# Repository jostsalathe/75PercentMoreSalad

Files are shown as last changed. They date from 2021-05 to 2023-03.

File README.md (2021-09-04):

# 75PercentMoreSalad

## Keychron low profile optical switches

- plate thicknes 1.2 mm
- plate cutout 14 * 14 mm²
- plate distance from pcb 1.3 mm
- pcb center hole 3.3 mm (2.4 mm below pcb surface)
- clip cutouts 11 mm apart, 2 mm wide, 5 mm long
- illumination LED within 4 and 6 mm above switch center, 3 mm long, 1.35 mm high
- 

## Stabilizer options

- Costar mounted to the PCB instead of the plate
- Kailh Choc Stabilizers (couldn't find 6.25U, yet, only [2U](https://spacecat.design/products/kailh-2u-choc-stabilizer-low-profile) ([KiCAD footprint](https://github.com/keebio/Keebio-Parts.pretty/blob/master/Kailh-PG1350-2u.kicad_mod))...)

## Parts for PCB

| Reference | Count | Value | Mfr. # | LCSC # |
|:-:|:-:|:-:|-|-|
| D1-D85 | 85 | LED IR |  |  |
| D86 | 1 | 1N5819 |  |  |
| D87 | LED Red |  |  |  |
| D88 |  |  |  |  |
|  |  |  |  |  |

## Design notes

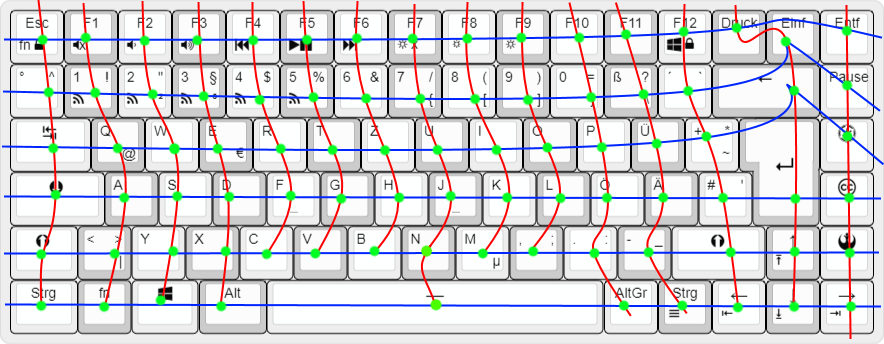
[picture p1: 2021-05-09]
75PercentMoreSaladMatrix.png

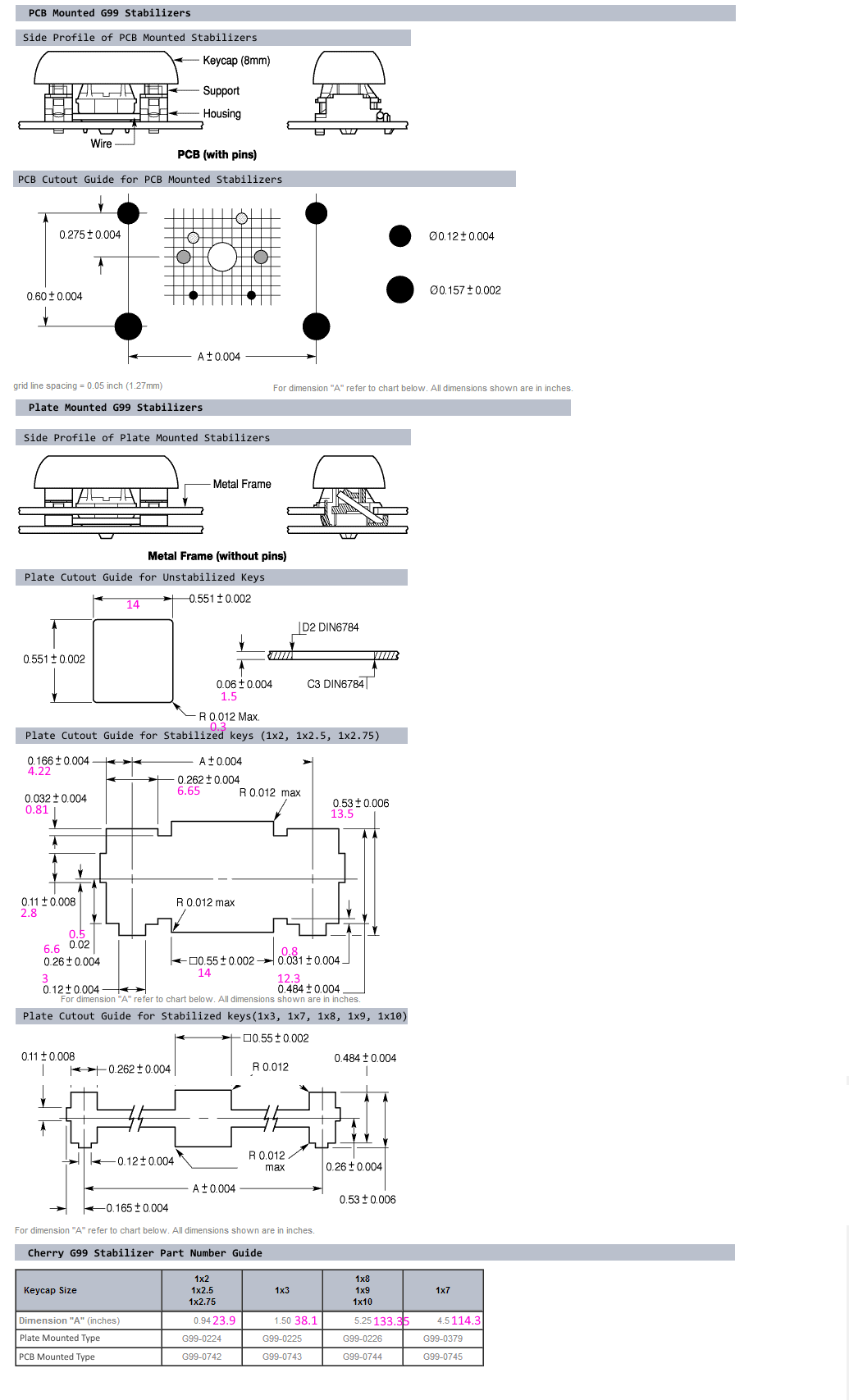
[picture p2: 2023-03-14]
case/StabiMounting.png

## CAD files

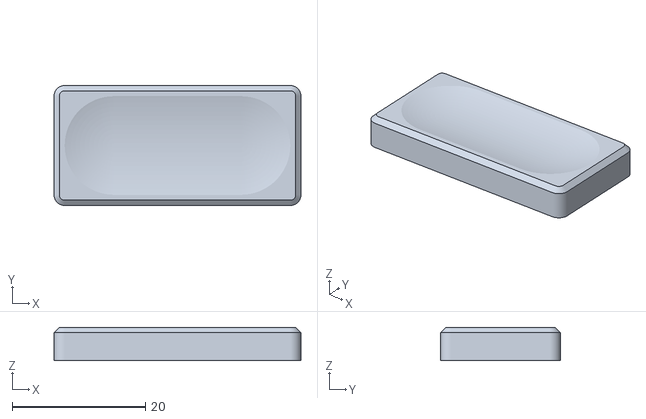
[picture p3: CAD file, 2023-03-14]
case/keycaps/keycap_full_2U.stl
37.0 x 18.0 x 5.00

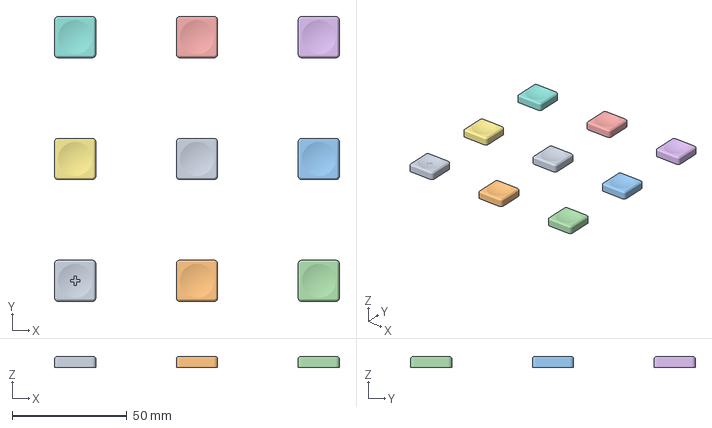
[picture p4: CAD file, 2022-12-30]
case/keycaps/keycap_full.3mf
124.0 x 124.0 x 5.00 mm
keycap_full.stl
keycap_full_home.stl

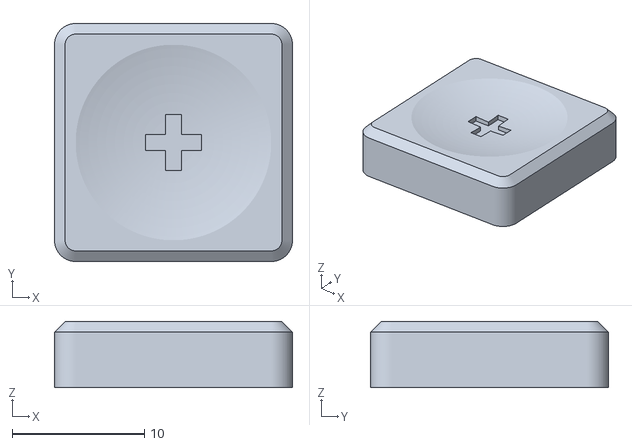
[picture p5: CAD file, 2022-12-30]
case/keycaps/keycap_full_home.stl
18.0 x 18.0 x 5.00

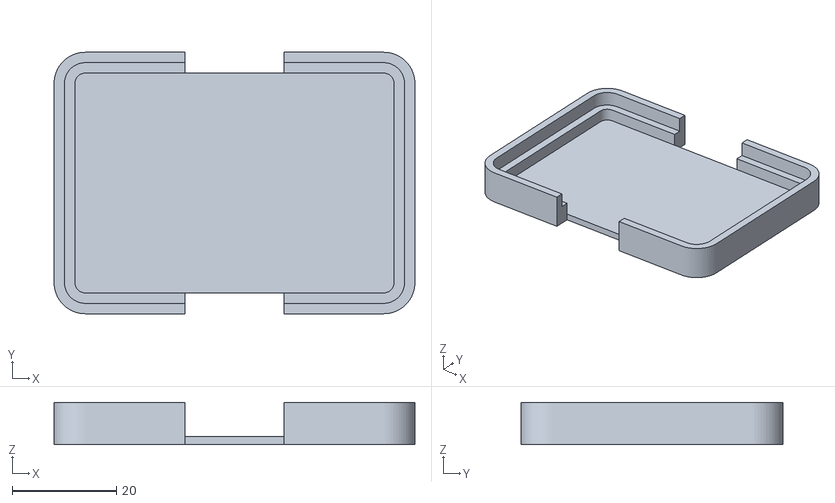
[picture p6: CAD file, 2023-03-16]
case/caseTest.stl
69.2 x 50.1 x 8.10

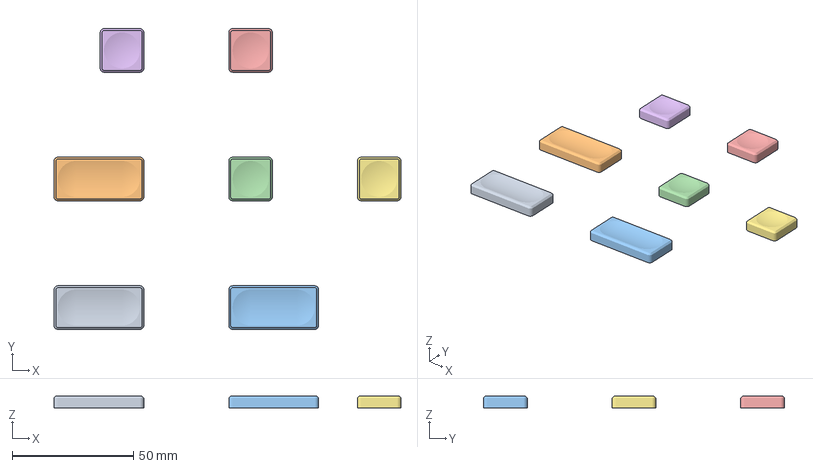
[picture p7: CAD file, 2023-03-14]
case/keycaps/keycaps_for_tester.3mf
143.0 x 124.0 x 5.00 mm
keycap_full_2U.stl
keycap_full.stl

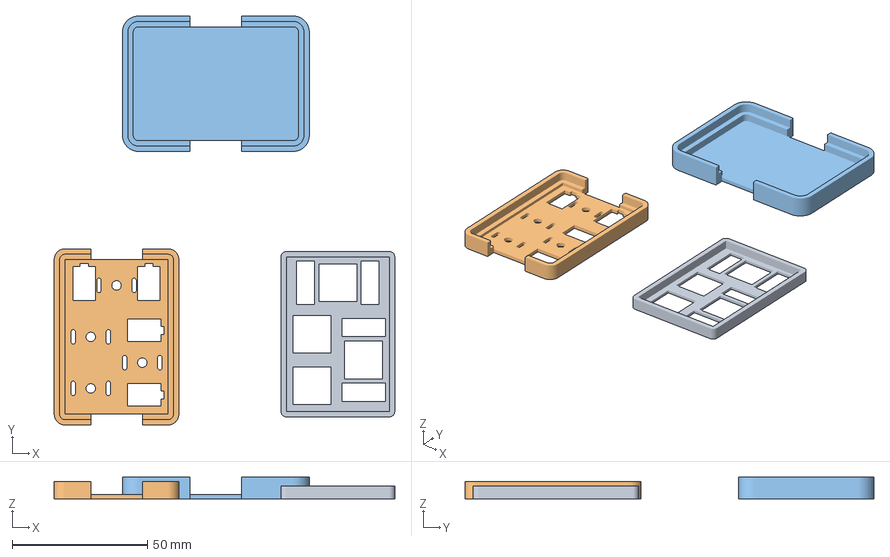
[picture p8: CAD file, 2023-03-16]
case/test.3mf
126.0 x 151.3 x 8.10 mm
plateTest.stl
pcbTest.stl
caseTest.stl

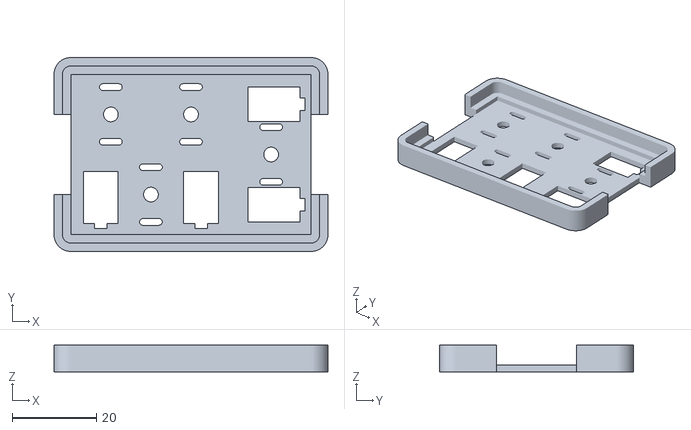
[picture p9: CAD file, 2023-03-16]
case/pcbTest.stl
65.2 x 46.1 x 6.40

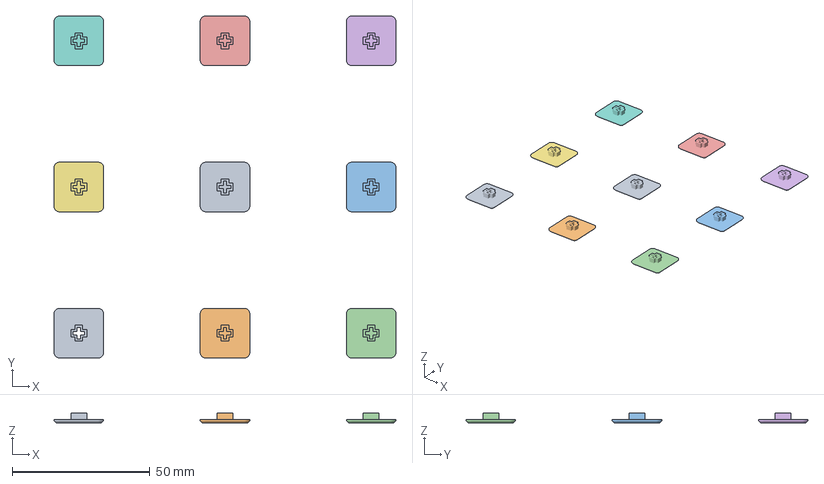
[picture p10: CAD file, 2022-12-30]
case/keycaps/keycap_floating.3mf
124.0 x 124.0 x 3.60 mm
keycap_floating.stl
keycap_floating_home.stl

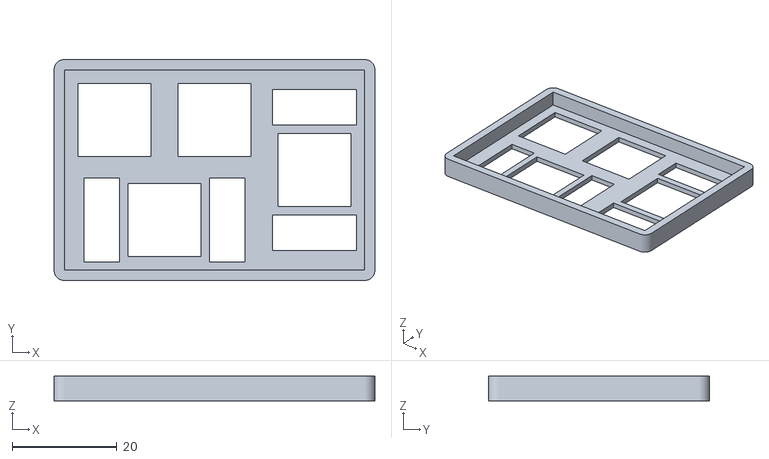
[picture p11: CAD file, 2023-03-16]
case/plateTest.stl
61.2 x 42.1 x 4.70

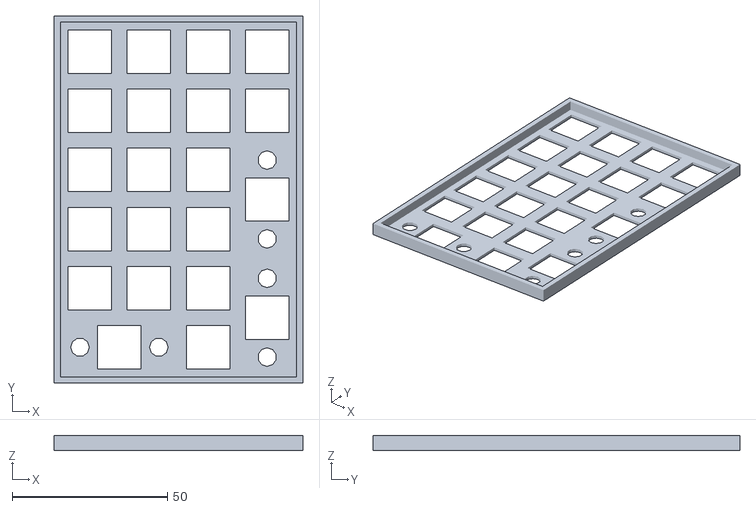
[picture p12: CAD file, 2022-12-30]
case/plateNum.stl
80.2 x 118.3 x 4.70

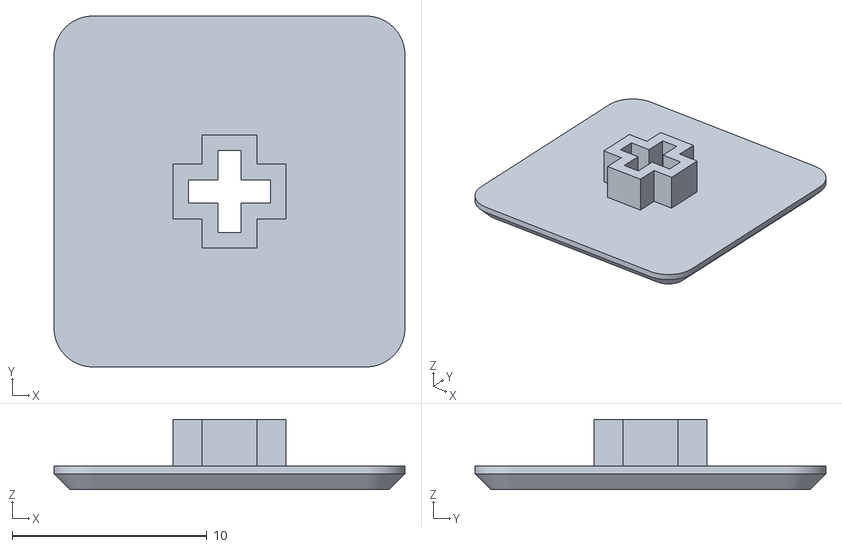
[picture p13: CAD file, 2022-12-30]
case/keycaps/keycap_floating_home.stl
18.0 x 18.0 x 3.60

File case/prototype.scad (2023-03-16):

$fn=$preview?12:64;

zCase = 1.6;
zCaseToPcb = 3;

zPcb = 1.6;
zPcbToPlate = 1.3;

zPlate = 1.2;
zPlateRim = 3.5;


tWall = 2;
xySwitchCutout = 14;

switchPitch = 19.05;
switchStemHole = 3.5;
xSwitchClipSlot = 5.4;
ySwitchClipSlot = 1.6;
ySwitchClipSlotDist = 6.5;

xStabiDist2U = 23.876;
xStabiPlate = 6.7;
yStabiPlate = 16;

// Array of rows with row = [[xOffset, yOffset], [sw0, sw1, ..., swN]] where
//  swI can be 0 (no switch), 1 (1U), 2 (2U horizontal) or 3 (2U vertical)
// This array follows a strict raster, so space occupied by a 2 or 3 has to
//  be reserved with a corresponding 0.
layoutTest =
[
  [1, 1, 0],
  [2, 0, 3]
];

layoutNum =
[
  [1, 1, 1, 1],
  [1, 1, 1, 1],
  [1, 1, 1, 0],
  [1, 1, 1, 3],
  [1, 1, 1, 0],
  [2, 0, 1, 3]
];

layout75 =
[
  [1,    1, 1, 1, 1, 1, 1, 1, 1, 1, 1, 1, 1, 1, 1, 1],
  [1,    1, 1, 1, 1, 1, 1, 1, 1, 1, 1, 1, 1, 2, 0, 1],
  [1.5,  1, 1, 1, 1, 1, 1, 1, 1, 1, 1, 1, 1, 0, 1, 1],
  [1.75, 1, 1, 1, 1, 1, 1, 1, 1, 1, 1, 1, 1, 3, 1, 1],
  [1.25, 1, 1, 1, 1, 1, 1, 1, 1, 1, 1, 1, 1, 1, 1, 1],
  [1,    1, 1, 1, 2, 0, 2, 0, 2, 0, 1, 1, 1, 1, 1, 1]
];

module switch1U()
{
  translate([0, 0, zPlate/2])
  cube([xySwitchCutout, xySwitchCutout, zPlate+0.2], center=true);
}

module switch2U()
{
  translate([switchPitch/2, 0, 0])
  {
    switch1U();
    translate([0, 0, zPlate/2])
    {
      for(xPos = [-1, 1])
      translate([xPos * xStabiDist2U/2, 0, 0])
      {
        cube([xStabiPlate, yStabiPlate, zPlate+0.2], center=true);
      }
    }
  }
}

module pcbSwitch1U()
{
  translate([0, 0, zPcb/2])
  {
    cylinder(h=zPcb+0.2, d=switchStemHole, center=true);
    for (yOffset = [-ySwitchClipSlotDist, ySwitchClipSlotDist])
    translate([0, yOffset, 0])
    {
      translate([-(xSwitchClipSlot-ySwitchClipSlot)/2, 0, 0])
      cylinder(h=zPcb+0.2, d=ySwitchClipSlot, center=true);
      cube([xSwitchClipSlot-ySwitchClipSlot, ySwitchClipSlot, zPcb+0.2], center=true);
      translate([(xSwitchClipSlot-ySwitchClipSlot)/2, 0, 0])
      cylinder(h=zPcb+0.2, d=ySwitchClipSlot, center=true);
    }
  }
}

module pcbStabi()
{
  xMain = 8.3;
  yMain = 12.4;
  yMainOffset = -0.7;

  xWire = 3;
  yWire = 1.2;
  yWireOffset = -yMain/2+yMainOffset-yWire/2;

  translate([0, yMainOffset, 0]) cube([xMain, yMain, zPcb+0.2], center=true);
  translate([0, yWireOffset+0.1, 0]) cube([xWire, yWire+0.1, zPcb+0.2], center=true);
}

module pcbSwitch2U(rotated=false)
{
  translate([switchPitch/2, 0, 0])
  {
    rotate([0,0,rotated?-90:0]) pcbSwitch1U();
    translate([0, 0, zPcb/2])
    {
      translate([-xStabiDist2U/2, 0, 0]) pcbStabi();
      translate([xStabiDist2U/2, 0, 0]) pcbStabi();
    }
  }
}

module switches(layout, isPcb=false)
{
  for (iRow = [0:len(layout)-1])
  {
    firstSwitch = layout[iRow][0];
    offsetX = firstSwitch<2 ? firstSwitch-1 : 0;
    for (iCol = [0:len(layout[iRow])-1])
    {
      posX = (iCol==0 ? offsetX/2 : offsetX + iCol) * switchPitch;
      posY = -iRow * switchPitch;
      translate([posX, posY, 0])
      {
        if (layout[iRow][iCol] < 1);
        else if (layout[iRow][iCol] < 2)
        {
          if(isPcb) pcbSwitch1U();
          else switch1U();
        }
        else if (layout[iRow][iCol] == 2)
        {
          if(isPcb) pcbSwitch2U();
          else switch2U();
        }
        else if (layout[iRow][iCol] == 3) rotate([0, 0, 90])
        {
          if(isPcb) pcbSwitch2U(true);
          else switch2U();
        }
      }
    }
  }
}

module plate(layout)
{
  xPlate = len(layout[0]) * switchPitch;
  yPlate = len(layout) * switchPitch;
  difference()
  {
    translate([tWall, -yPlate - tWall, 0])
    minkowski()
    {
      cube([xPlate, yPlate, zPlateRim]);
      cylinder(h=zPlate, r=tWall);
    }
    translate([tWall, -yPlate - tWall, zPlate])
    cube([xPlate, yPlate, zPlateRim + 0.1]);
    translate([switchPitch/2 + tWall, -switchPitch/2 - tWall, 0])
    switches(layout);
  }
}

module pcb(layout)
{
  xPcb = len(layout[0]) * switchPitch;
  yPcb = len(layout) * switchPitch;
  difference()
  {
    // outer contours
    translate([2*tWall, -yPcb - 2*tWall, 0])
    minkowski()
    {
      cube([xPcb, yPcb, zPcbToPlate + zPlateRim]);
      cylinder(h = zPcb, r = 2*tWall);
    }
    // cutout plate
    translate([2*tWall, -yPcb - 2*tWall, zPcb + zPcbToPlate])
    minkowski()
    {
      cube([xPcb, yPcb, zPlateRim + 0.1]);
      cylinder(h=zPlate, r=tWall);
    }
    // cutout parts on pcb top side
    translate([2*tWall, -yPcb - 2*tWall, zPcb])
    cube([xPcb, yPcb, zPcbToPlate + 0.1]);
    // pcb cutouts
    translate([switchPitch/2 + 2*tWall, -switchPitch/2 - 2*tWall, 0])
    switches(layout, true);
    // wall cutouts
    for(xPos = [2*tWall + xPcb, -0.1])
    translate([xPos, -2*tWall - yPcb/2 - switchPitch/2, -0.1])
    cube([2*tWall + 0.1, switchPitch, zPcb + 0.2]);
    translate([-0.1, -2*tWall - yPcb/2 - switchPitch/2, zPcb])
    cube([xPcb + 4*tWall + 0.2, switchPitch, zPcbToPlate + zPlateRim + 0.1]);
  }
}

module case(layout)
{
  xCase = len(layout[0]) * switchPitch;
  yCase = len(layout) * switchPitch;
  difference()
  {
    // outer contours
    translate([3*tWall, -yCase - 3*tWall, 0])
    minkowski()
    {
      cube([xCase, yCase, zCaseToPcb + zPlateRim]);
      cylinder(h = zCase, r = 3*tWall);
    }
    // cutout pcb
    translate([3*tWall, -yCase - 3*tWall, zCase + zCaseToPcb])
    minkowski()
    {
      cube([xCase, yCase, zPcbToPlate + zPlateRim + 0.1]);
      cylinder(h = zPcb, r = 2*tWall);
    }
    // cutout parts on pcb bottom side
    translate([3*tWall, -yCase - 3*tWall, zCase])
    minkowski()
    {
      cube([xCase, yCase, zCaseToPcb]);
      cylinder(h = 0.1, r = tWall);
    }
    // wall cutouts
    for(yPos = [-2*tWall, -yCase - 6*tWall - 0.1])
    translate([3*tWall + xCase/2 - switchPitch/2, yPos, -0.1])
    cube([switchPitch, 2*tWall + 0.1, zCase + 0.2]);
    translate([3*tWall + xCase/2 - switchPitch/2, -yCase - 6*tWall - 0.1, zCase])
    cube([switchPitch, yCase + 6*tWall + 0.2, zCaseToPcb + zPcb + zPcbToPlate + zPlateRim + 0.1]);
  }
}

case(layoutTest);

translate([tWall, -tWall, zCase + zCaseToPcb])
pcb(layoutTest);

translate([2*tWall, -2*tWall, zCase + zCaseToPcb + zPcb + zPcbToPlate])
plate(layoutTest);

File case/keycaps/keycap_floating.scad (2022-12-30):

zCav = 2.4;

zStemExtra = 1;
zStem = zCav + zStemExtra;
tCross = 1.2;
wCross = 4.2;
dStem = 5.8;
tWallStem = 0.8;

xyCap = 18;
zCap = zStemExtra + 0.2;
capChamfer = 0.8;

rFillet = 2;

module keycap(isHome=false)
{
  difference()
  {
    union()
    {
      translate([0, 0, zCav]) minkowski()
      {
        cube([xyCap-2*rFillet, xyCap-2*rFillet, zCap-capChamfer]);
        translate([rFillet, rFillet, 0])
        cylinder(h=capChamfer, r1=rFillet, r2=rFillet-capChamfer, $fn=64);
      }
      translate([xyCap/2, xyCap/2, zStem/2])
      {
        *cylinder(h=zStem, d=dStem, center=true, $fn=64);
        cube([wCross+2*tWallStem, tCross+2*tWallStem, zStem], center=true);
        cube([tCross+2*tWallStem, wCross+2*tWallStem, zStem], center=true);
      }
    }
    translate([xyCap/2, xyCap/2, zStem/2-(isHome?0:1)])
    {
      cube([wCross, tCross, zStem+2], center=true);
      cube([tCross, wCross, zStem+2], center=true);
    }
  }
}

difference()
{
  translate([0, 0, zCap+zCav]) rotate([180, 0, 90]) keycap(false);
  translate([xyCap/2, -1, -1])
  *cube([xyCap/2+1, xyCap+2, zCav+zCap+2]);
  translate([-1, -1, -1])
  *cube([xyCap/2+1, xyCap+2, zCap+2]);
}

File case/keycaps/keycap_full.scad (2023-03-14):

switchPitch = 19.05;
xyCav = 14.8;
zCav = 3.4;

zStem = zCav;
tCross = 1.2;
wCross = 4.2;
dStem = 5.8;
tWallStem = 0.8;

xyCap = 18;
zCap = zCav + 1.6;
capChamfer = 0.8;

tWall = (xyCap - xyCav) / 2;

zDimple = 1;
rDimple = (xyCap - 4 * capChamfer) / 2;
rDimpleSphere = (zDimple + rDimple^2 / zDimple) / 2;

module stem()
{
  difference()
  {
    // stem meat
    translate([0, 0, zStem/2])
    {
      cube([wCross+2*tWallStem, tCross+2*tWallStem, zStem], center=true);
      cube([tCross+2*tWallStem, wCross+2*tWallStem, zStem], center=true);
    }
    // stem cavity
    translate([0, 0, zStem/2-2])
    {
      cube([wCross, tCross, zStem+4], center=true);
      cube([tCross, wCross, zStem+4], center=true);
    }
  }
}

module keycap(size=1, isHome=false)
{
  xExtra = (size-1) * switchPitch;
  difference()
  {
    union()
    {
      difference()
      {
        // main cap body
        minkowski()
        {
          cube([xyCav+xExtra, xyCav, zCap-capChamfer]);
          translate([tWall, tWall, 0])
          cylinder(h=capChamfer, r1=tWall, r2=tWall-capChamfer, $fn=64);
        }
        // main cavity
        translate([tWall, tWall, -1])
        cube([xyCav+xExtra, xyCav, zCav+1]);
      }
      // stem
      translate([(xyCap+xExtra)/2, xyCap/2, 0])
      {
        stem();
        // extra stems for stabilizer
        if (size >= 2) {
          stabiWidth = size>7 ? 133.35 : size>=7 ? 114.3 : size>=6.25 ? 38.1 : size>=6 ? 38.1 : size>=3 ? 38.1 : 23.9;
          translate([-stabiWidth/2, 0, 0]) stem();
          translate([stabiWidth/2, 0, 0]) stem();
        }
      }
    }
    // dimple
    translate([xyCap/2, xyCap/2, zCap+rDimpleSphere-zDimple])
    {
      $fn=$preview?64:256;
      sphere(rDimpleSphere);
      if (size>1)
      {
        translate([xExtra, 0, 0])
        sphere(rDimpleSphere);
        rotate([90, 180/$fn, 90])
        cylinder(h=xExtra, r=rDimpleSphere);
      }
    }
    // home mark
    if (isHome) translate([(xyCap+xExtra)/2, xyCap/2, (zCap-zCav)/2+zCav+0.2])
    {
      cube([wCross, tCross, zCap-zCav], center=true);
      cube([tCross, wCross, zCap-zCav], center=true);
    }
  }
}

difference()
{
  *keycap(1, false);
  keycap(2, false);
  *translate([-1, -1, -1]) cube([xyCap+2+9*switchPitch, xyCap/2+1, zCap+2]); // section near xz
  *translate([-1, xyCap/2, -1]) cube([xyCap+2+9*switchPitch, xyCap/2+1, zCap+2]); // section far xz
}

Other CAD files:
case/keycaps/keycap_floating.stl
case/keycaps/keycap_full.stl

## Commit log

2021-05-07 Created KiCAD project and copied libraries from nrfmicro project.
    [75PercentMoreSalad.kicad_pcb, 75PercentMoreSalad.sch]
2021-05-08 built key matrix with generic symbols for now.
    [75PercentMoreSalad.sch]
2021-05-09 copied more stuff from nRFMicro 1.4
    [75PercentMoreSalad.sch]
2021-05-09 Added LED drive N-MOSFETs and assigned matrix signals to MCU pins. MCU has too few pins at the moment. Solvable by omitting the 32kHz quartz or by multiplexing the LED signals.
    [75PercentMoreSalad.kicad_pcb, 75PercentMoreSalad.sch, key.sch]
2021-09-04 Started work on numpad variant for proof of concept.
    [75PercentMoreSalad.sch, key.sch]
2022-01-11 Migrated KiCAD project to KiCAD 6.0
    [75PercentMoreSalad.kicad_pcb, 75PercentMoreSalad.kicad_sch, 75PercentMoreSalad.sch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]
2022-12-12 Added pi filters to USB and battery power, added TVS diode package to USB data lines, added Numlock LED channel.
    [75PercentMoreSalad.kicad_sch, key.kicad_sch]
2022-12-30 Added 3D source files for simple keycaps. Added simplistic plate for a numpad.
    [keycap_floating.3mf, keycap_floating.scad, keycap_floating.stl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]
2022-12-31 Changed stabilizer hole distance to correct value.
    [prototype.scad]
2023-03-14 Modified keycap_full design to support keycaps larger than 1U. Added PCB dummy.
    [keycap_full.scad, keycap_full_2U.stl, keycaps_for_tester.3mf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]
2023-03-14 Corrections after printing the test case.
    [pcbTest.stl, plateTest.stl, prototype.scad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]
2023-03-16 Corrected dimensions, rounded corners and added case.
    [caseTest.stl, pcbTest.stl, plateTest.stl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]
